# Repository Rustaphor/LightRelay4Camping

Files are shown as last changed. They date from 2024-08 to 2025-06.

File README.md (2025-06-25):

LightRelay4Camping ⛺🌳⛰️
==========================
 

Проект аналогового микромощного фотореле с питанием от PowerBank (USB Type-C) для управления включение-отключение USB-гирлянд
(напряжения питания 5В) в ночное время суток в широким диапазоне регулировки пороговых уровней чувствительности к темноте.
Это простое и надежное DIY устройство целиком аналоговое без прошивок, его несложно повторить начинающему радиолюбителю.
На фото ниже представлен внешний вид собранной электронной платы и устройства в корпусе.

Фото электронной платы сверху в корпусе

**Фото устройства в корпусе**

## Для чего нужно?
Устройство будет очень полезным в местах кемпинга и отдыха при освещении гирляндами с питанием от PowerBank-ов.
Светодиодные USB-гирлянды, украшающие палатку/автомобиль или другое место размещения на природе с помощью данного устройства
станут автономно-управляемые по уличной освещенности. Самостоятельно включаться в ночное время суток и также отключаться
на рассвете, тем самым экономя заряд PowerBank-а.

[Go to documentation][1]

## Особенности девайса
Фотореле спроектировано просто и надежно. Технически проект представляет несложную реализацию электронной аналоговой
схемотехники (см. _принципиальную схему_) и стандартной цифровой логики (без микроконтроллеров и прошивок), что делает прибор
микро мощным малопотребляемым. А также последнее обстоятельство делает удобным повторение DIY, например в учебной практике.
Для построения электронной схемы выбраны современные широкодоступные электронные компоненты. Ниже кратко представлены
основные достоинства устройства:

- :white_check_mark: Сверхнизкое энергопотребление, значение всего 1мА (в светлое время);
- :white_check_mark: Широкий диапазон регулирования чувствительности срабатывания. От крайне темного, едва видное глазу до рассвета,
когда уже гирлянды не нужны;
- :white_check_mark: Питание 5В от повербанка USB Type-C;
- :white_check_mark: Встроенный супперконденсатор и схема его заряда для решение проблемы самоотключения PowerBank-ов. В ждущем режиме фотореле питается от собственного суперконденсатора.
  Емкости суперконденсатора хватает на 4 часа автономной работы;
- :white_check_mark: Небольшая встроенная временная задержка включения/отключения для минимизации ложных срабатываний часто меняющейся
освещенности, например, под качающимися кронами деревьев;
- 🎁 В качестве бонуса к проектe приложены исходные файлы корпуса для 3D-печати. Корпус имеет следующие особенности:
  - ☔︎ Влагозащищенный
  - 👁 Поворотный глазок с датчиком освещенности (направляется в небо)
  - 🧲 Магнитное крепление 
  
Фото электронной платы сверху в корпусе

**Фото устройства со снятой верхней крышкой**

> [!TIP]
> PowerBank-и имеют особенность работы. Они предназначены для питания сравнительно мощных нагрузок. Если ток
> потребления нагрузкой слишком мал (менее 50…100мА), то через небольшой промежуток времени PowerBank переходит в режим
> «сна» (выключается), нагрузка полностью обесточивается.

:blue_book: [Полная техническая документация][1] содержит подробное описание принципа работы, инструкции к изготовлению.

> [!IMPORTANT]
> Подключение устройства к PowerBank-у рекомендуется кабелем *USB: type-C + type-C*. При использовании кабеля *USB: Type-A + Type-C*, автоматическое включение
> PowerBank-а негарантировано (зависит от особенностей конкретного PowerBank-а).

<details>
<summary>:paperclip: Файлы проекта</summary>

## Файлы проекта
Проект состоит из нижеследующих файлов и папок:

**Проектные файлы электронной схемы и печатной платы** в формате [KiCad EDA](https://www.kicad.org/) v8.0, содержат
электронную схему, печатную плату (ПП), правила её трассировки, сопутствующие компоненты (посадочные места, 3D-модели).

```
📄 Camping-LightRelay.kicad_*
📄 lsensor-module.kicad_sch
📄 custom.kicad_sym
📄 fp-lib-table
📄 sym-lib-table
📂 [lib.pretty]
📂 [3dshapes]
```

**Файлы симуляции**
Файлы симуляция [SPICE](https://ru.wikipedia.org/wiki/SPICE_(%D1%81%D0%B8%D0%BC%D1%83%D0%BB%D1%8F%D1%82%D0%BE%D1%80_%D1%8D%D0%BB%D0%B5%D0%BA%D1%82%D1%80%D0%BE%D0%BD%D0%BD%D1%8B%D1%85_%D1%81%D1%85%D0%B5%D0%BC))
отдельных узлов содержатся в отдельной директории

```
📂 [Sims]
```
</details>

[1]: https://github.com/Rustaphor/LightRelay4Camping/wiki "Перейти в раздел Wiki"

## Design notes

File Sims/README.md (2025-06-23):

## Файлы симуляции схемы


Файлы в этой директории предназначены для программного продукта симулятора электронных схем [Micro-Cap 12][1]. Чтобы открыть требуется установить соответствующее ПО
со стандартными библиотеками компонентов. Файлы в данной директории не локализованы и не содержат библиотечных компонентов. Данные файлы полезны если требуется внести
какие-то изменения в работу схемы, заменить аналогами или пересчитать номиналы. Если Вам просто нужно повторить уже готовую схему, эти файлы и директория не нужны.

> [!IMPORTANT]
> Раздел предназначен для опытных пользователей, понимающих теорию цепей и принципы разработки электронных устройств посредством моделирования
> [SPICE](https://ru.wikipedia.org/wiki/SPICE_(%D1%81%D0%B8%D0%BC%D1%83%D0%BB%D1%8F%D1%82%D0%BE%D1%80_%D1%8D%D0%BB%D0%B5%D0%BA%D1%82%D1%80%D0%BE%D0%BD%D0%BD%D1%8B%D1%85_%D1%81%D1%85%D0%B5%D0%BC))-подобным
> Симуляция электронных устройств выходит за рамки настоящей технической документации, начинающему пользователю многое будет непонятно. :exploding_head:

Подробная [техническая документация по симуляции в технической документации](https://github.com/Rustaphor/LightRelay4Camping/wiki/%D0%9C%D0%BE%D0%B4%D0%B5%D0%BB%D0%B8%D1%80%D0%BE%D0%B2%D0%B0%D0%BD%D0%B8%D0%B5-%D1%81%D1%85%D0%B5%D0%BC%D1%8B)

[1]: https://ru.wikipedia.org/wiki/Micro-Cap "Micro-Cap wiki"

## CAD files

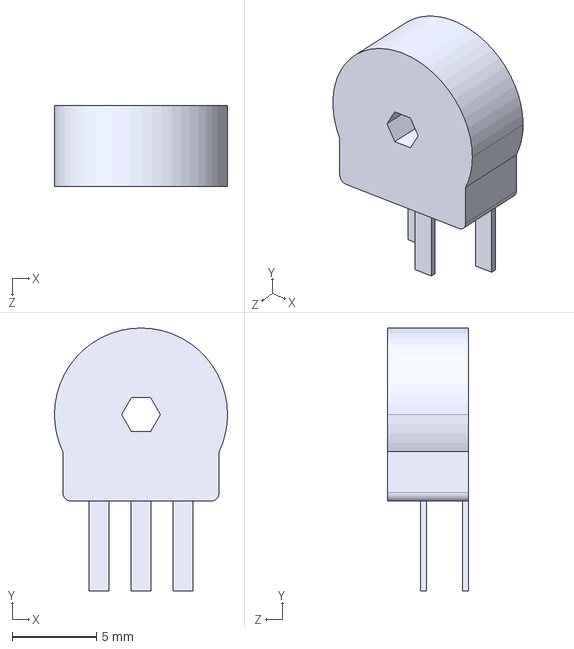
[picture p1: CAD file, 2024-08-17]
3dshapes/PTN10-AH.STEP
10.3 x 15.7 x 4.80 mm

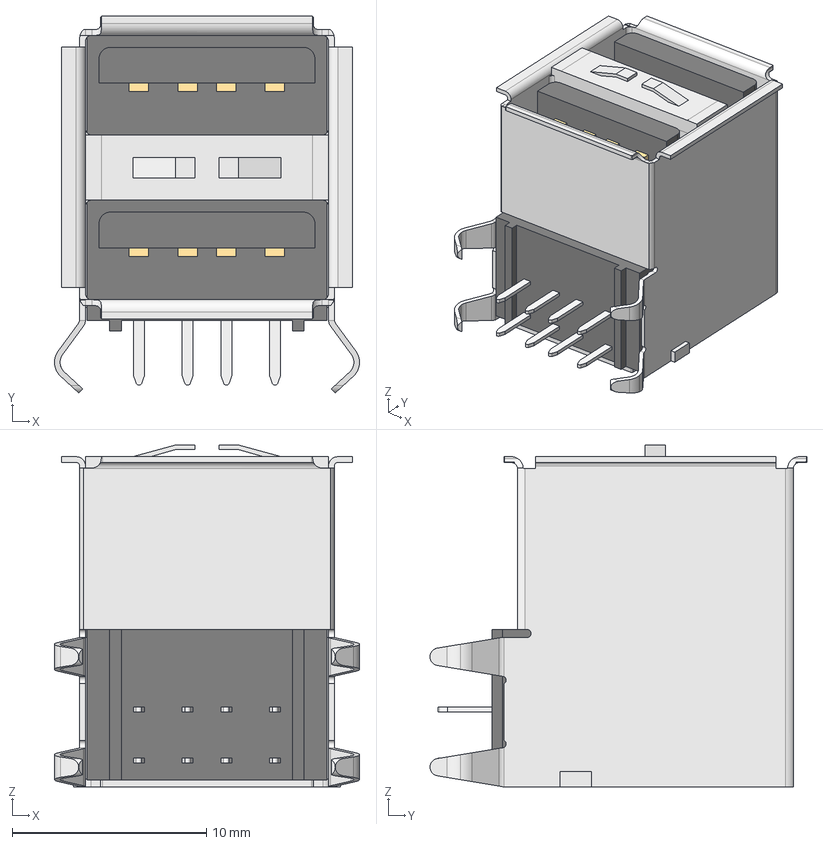
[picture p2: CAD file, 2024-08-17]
3dshapes/usb_a_dual_port_dip.stp
15.7 x 19.4 x 17.6 mm

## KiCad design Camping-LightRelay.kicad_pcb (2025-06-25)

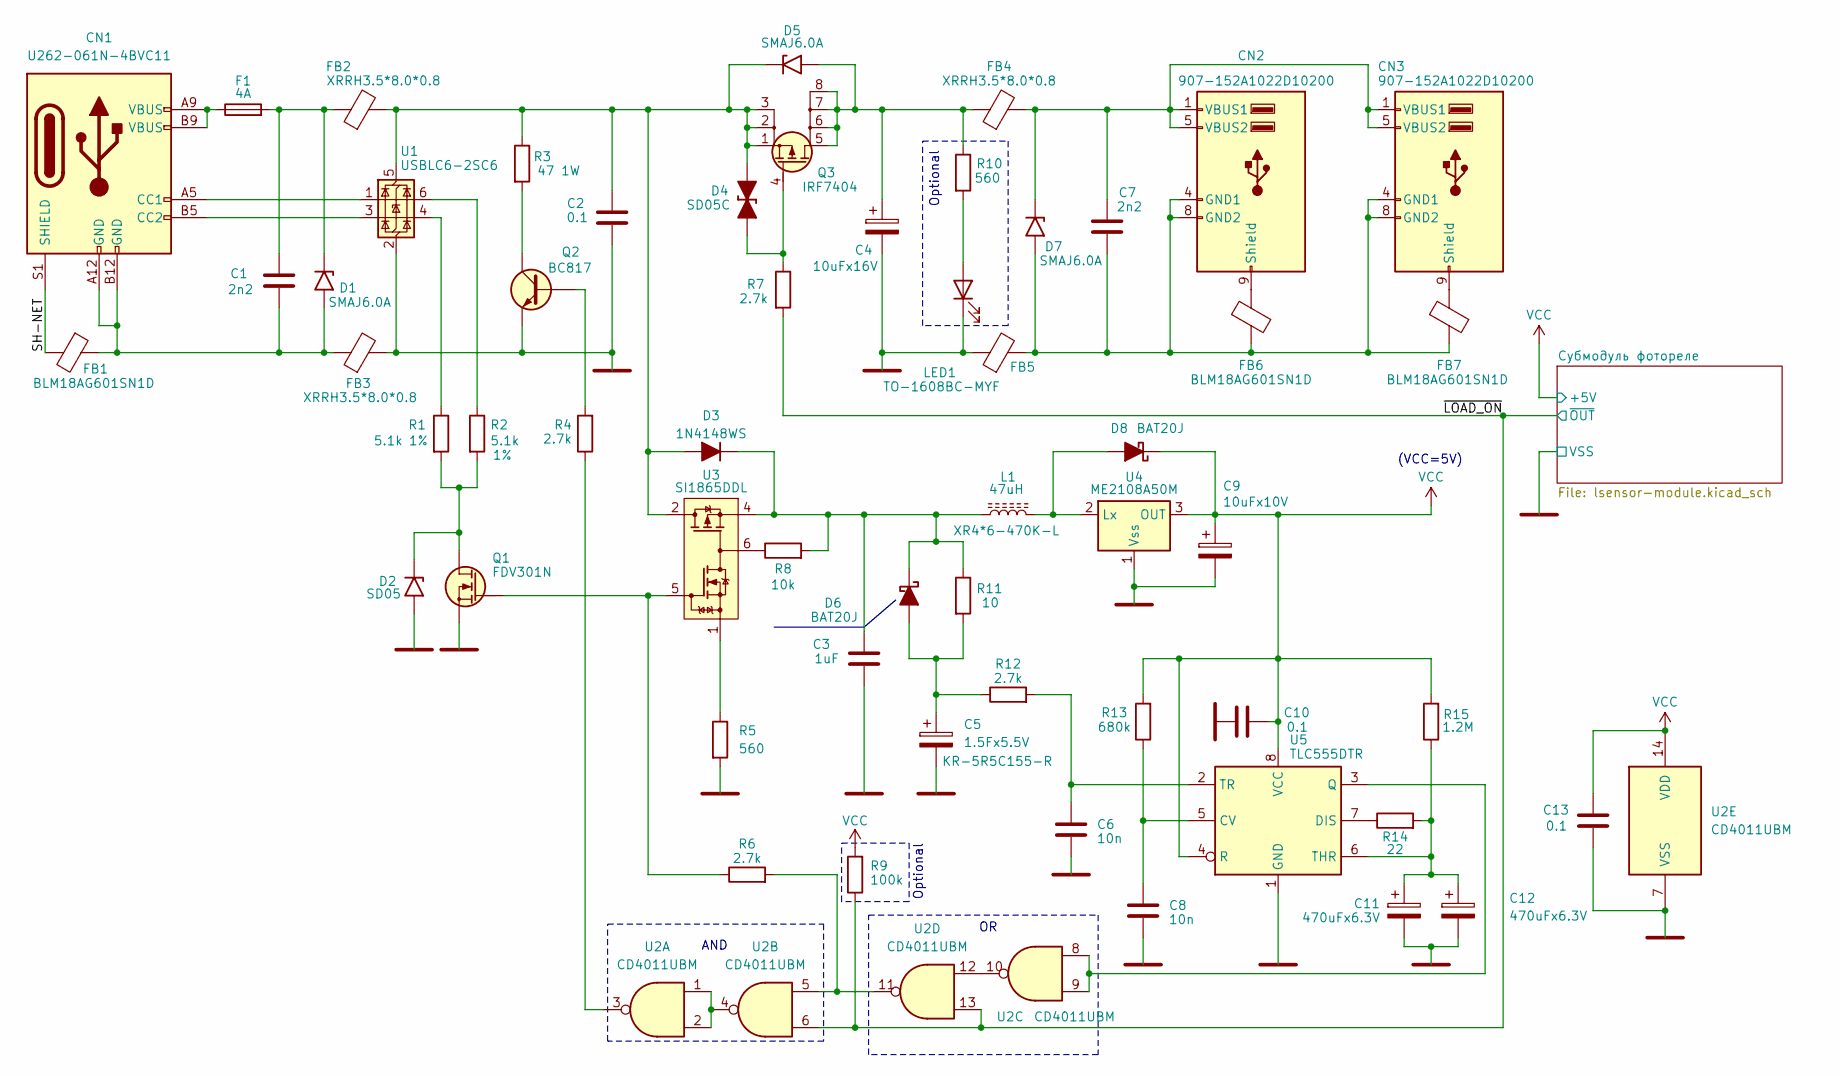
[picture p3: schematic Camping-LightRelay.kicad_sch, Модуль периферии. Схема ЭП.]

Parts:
C1, C7: 2n2; C_Disc_D7.5mm_W5.0mm_P7.50mm; Part Number CY2222MD1PEE47J2A8
C2, C10, C13: 0.1; C_0603_1608Metric
C3: 1uF; C_0805_2012Metric
C4: 10uFx16V; CP_EIA-3216-12_Kemet-S_Pad1.58x1.35mm_HandSolder; Part Number CA45-B010K107T
C5: 1.5Fx5.5V; Eaton_KR-5R5C155; Part Number KR-5R5C155-R
C6, C8: 10n; C_0603_1608Metric
C9: 10uFx10V; CP_EIA-3216-12_Kemet-S_Pad1.58x1.35mm_HandSolder; Part Number TC212A106K010Y
C11, C12: 470uFx6.3V; CP_EIA-7343-31_Kemet-D_Pad2.25x2.55mm_HandSolder; Part Number TAJD477K006RNJ
CN1: U262-061N-4BVC11; USB_C_Receptacle_GCT_USB4125-xx-x-0190_6P_TopMnt_Horizontal
CN2, CN3: 907-152A1022D10200; USB_A_DUAL_PORT_Horizontal_Stacked
D1, D5, D7: SMAJ6.0A; D_SMA
D2: SD05; D_SOD-323_HandSoldering
D3: 1N4148WS; D_SOD-323_HandSoldering
D4: SD05C; D_SOD-323_HandSoldering
D6, D8: BAT20J; D_SOD-323_HandSoldering
F1: 4A; Fuse_1206_3216Metric_Pad1.42x1.75mm_HandSolder
FB1, FB6, FB7: BLM18AG601SN1D; L_0603_1608Metric
FB2, FB3, FB4, FB5: XRRH3.5*8.0*0.8; Ferrite_L8.0mm_D3.5mm_P3.81mm_Vertical
L1: 47uH; L_Radial_D6.0mm_P4.00mm; Part Number XR4*6-470K-L
LED1: TO-1608BC-MYF; LED_0603_1608Metric_Pad1.05x0.95mm_HandSolder
Q1: FDV301N; SOT-23
Q2: BC817; SOT-23
Q3: IRF7404; SO-8_3.9x4.9mm_P1.27mm
R1, R2: 5.1k; R_0603_1608Metric_Pad0.98x0.95mm; Tolerance 1%
R3: 47 1W; R_Axial_DIN0309_L9.0mm_D3.2mm_P2.54mm_Vertical
R4, R6, R12: 2.7k; R_0603_1608Metric_Pad0.98x0.95mm
R5: 560; R_0603_1608Metric_Pad0.98x0.95mm
R7: 2.7k; R_0603_1608Metric
R8: 10k; R_0603_1608Metric_Pad0.98x0.95mm
R9: 100k; R_0603_1608Metric_Pad0.98x0.95mm
R10: 560; R_0603_1608Metric
R11: 10; R_0805_2012Metric_Pad1.15x1.40mm
R13: 680k; R_0603_1608Metric_Pad0.98x0.95mm
R14: 22; R_0603_1608Metric_Pad0.98x0.95mm
R15: 1.2M; R_0603_1608Metric_Pad0.98x0.95mm
U1: USBLC6-2SC6; SOT-23-6
U2: CD4011UBM; SOIC-14_3.9x8.7mm_P1.27mm
U3: SI1865DDL; SOT-363_SC-70-6
U4: ME2108A50M; SOT-23-3
U5: TLC555DTR; SOIC-8_3.9x4.9mm_P1.27mm

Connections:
/SH-NET: CN1.S1 (SHIELD), FB1.2
/~LOAD_ON: R7.2, R9.1, U2.6, U2.13; also elsewhere on the board
GNDE: C2.2, C3.2, C4.2, C5.2, C6.2, C8.2, C9.2, C10.1, C11.2, C12.2, C13.2, D2.2 (A2), FB3.2, FB5.1, LED1.1 (K), Q1.2 (S), Q2.2 (E), R5.2, U1.2 (GND), U2.7 (VSS), U4.1 (Vss), U5.1 (GND); also elsewhere on the board
unnamed: CN1.A5 (CC1), U1.1 (I/O1)
unnamed: CN1.B5 (CC2), U1.3 (I/O2)
unnamed: CN1.A9 (VBUS), CN1.B9 (VBUS), F1.1
unnamed: C7.2, CN2.4 (GND1), CN2.8 (GND2), CN3.4 (GND1), CN3.8 (GND2), D7.2 (A2), FB5.2, FB6.1, FB7.1
unnamed: CN2.9 (Shield), FB6.2
unnamed: C7.1, CN2.1 (VBUS1), CN2.5 (VBUS2), CN3.1 (VBUS1), CN3.5 (VBUS2), D7.1 (A1), FB4.2
unnamed: CN3.9 (Shield), FB7.2
unnamed: C1.1, D1.1 (A1), F1.2, FB2.1
unnamed: C1.2, CN1.A12 (GND), CN1.B12 (GND), D1.2 (A2), FB1.1, FB3.1
unnamed: D2.1 (A1), Q1.3 (D), R1.2, R2.2
unnamed: C2.1, D3.2 (A), D4.1 (K), D5.1 (A1), FB2.2, Q3.1 (S), Q3.2 (S), Q3.3 (S), R3.1, U1.5 (VBUS), U3.2 (D2), U3.3 (D2)
unnamed: C3.1, D3.1 (K), D6.1 (K), L1.1, R8.2, R11.1, U3.4 (S2)
unnamed: D4.2 (A), Q3.4 (G), R7.1
unnamed: C4.1, D5.2 (A2), FB4.1, Q3.5 (D), Q3.6 (D), Q3.7 (D), Q3.8 (D), R10.1
unnamed: C5.1, D6.2 (A), R11.2, R12.1
unnamed: D8.2 (A), L1.2, U4.2 (Lx)
unnamed: LED1.2 (A), R10.2
unnamed: Q1.1 (G), R6.1, U3.5 (on/off)
unnamed: Q2.1 (B), R4.2
unnamed: Q2.3 (C), R3.2
unnamed: R1.1, U1.4 (I/O2)
unnamed: R2.1, U1.6 (I/O1)
unnamed: R4.1, U2.3
unnamed: R5.1, U3.1
unnamed: R6.2, U2.5, U2.11
unnamed: R8.1, U3.6
unnamed: U2.1, U2.2, U2.4
unnamed: U2.10, U2.12
unnamed: C8.1, R13.1, U5.5 (CV)
unnamed: R14.1, U5.7 (DIS)
unnamed: U2.8, U2.9, U5.3 (Q)
unnamed: C11.1, C12.1, R14.2, R15.1, U5.6 (THR)
unnamed: C6.1, R12.2, U5.2 (TR)
VCC: C9.1, C10.2, C13.1, D8.1 (K), R9.2, R13.2, R15.2, U2.14 (VDD), U4.3 (OUT), U5.4 (R), U5.8 (VCC); also elsewhere on the board

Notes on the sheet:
Optional
AND
(VCC=5V)

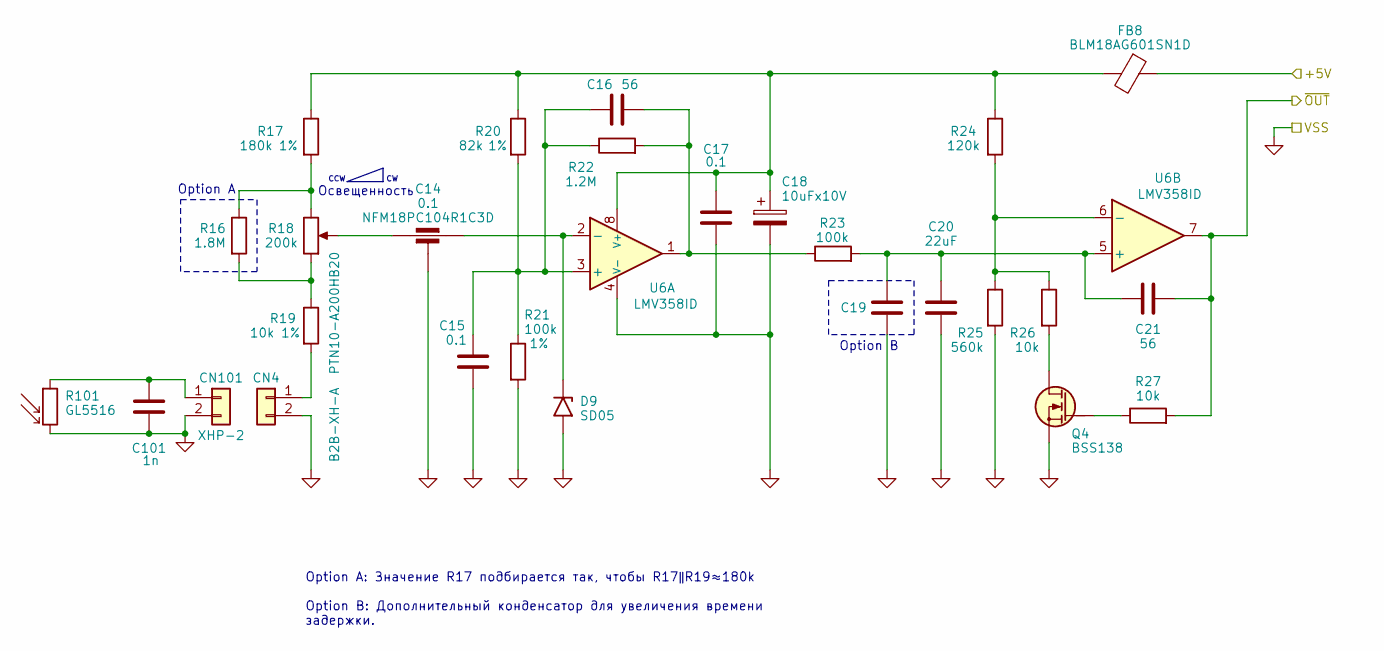
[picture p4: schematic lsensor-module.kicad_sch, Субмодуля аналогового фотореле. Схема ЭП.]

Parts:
C14: 0.1; C_0603_3-terminal; Part Number NFM18PC104R1C3D
C15, C17: 0.1; C_0603_1608Metric
C16, C21: 56; C_0603_1608Metric
C18: 10uFx10V; CP_EIA-3216-10_Kemet-I_Pad1.58x1.35mm_HandSolder; Part Number TC212A106K010Y
C19: 10uF; C_0805_2012Metric
C20: 22uF; C_0805_2012Metric
C101: 1n; C_0603_1608Metric
CN4: B2B-XH-A; JST_XH_B2B-XH-AM_1x02_P2.50mm_Vertical
CN101: XHP-2; PinSolder_1x2_P2.54mm
D9: SD05; D_SOD-323_HandSoldering
FB8: BLM18AG601SN1D; L_0603_1608Metric
Q4: BSS138; SOT-23
R16: 1.8M; R_0603_1608Metric
R17: 180k; R_0603_1608Metric; Tolerance 1%
R18: 200k; TRIM_PTN10-A01HB20; Part Number PTN10-A200HB20
R19: 10k; R_0603_1608Metric; Tolerance 1%
R20: 82k; R_0603_1608Metric; Tolerance 1%
R21: 100k; R_0603_1608Metric; Tolerance 1%
R22: 1.2M; R_0603_1608Metric
R23: 100k; R_0603_1608Metric
R24: 120k; R_0603_1608Metric
R25: 560k; R_0603_1608Metric
R26, R27: 10k; R_0603_1608Metric
R101: GL5516; R_LDR_5.1x4.3mm_P3.4mm_Vertical
U6: LMV358ID; SO-8_3.9x4.9mm_P1.27mm

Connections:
/~LOAD_ON: C21.2, R27.2, U6.7; also elsewhere on the board
GND2: C101.2, CN101.2, R101.2
GNDE: C14.2, C15.2, C17.2, C18.2, C19.2, C20.2, CN4.2, D9.2 (A2), Q4.2 (S), R21.2, R25.2, U6.4 (V-); also elsewhere on the board
unnamed: C16.2, R22.2, R23.1, U6.1
unnamed: CN4.1, R19.2
unnamed: C101.1, CN101.1, R101.1
unnamed: C14.3, D9.1 (A1), U6.2 (-)
unnamed: Q4.3 (D), R26.2
unnamed: Q4.1 (G), R27.1
unnamed: R16.2, R18.1 (A), R19.1
unnamed: R16.1, R17.2, R18.3 (E)
unnamed: C14.1, R18.2 (S)
unnamed: C15.1, C16.1, R20.2, R21.1, R22.1, U6.3 (+)
unnamed: C17.1, C18.1, FB8.2, R17.1, R20.1, R24.1, U6.8 (V+)
unnamed: C19.1, C20.1, C21.1, R23.2, U6.5 (+)
unnamed: R24.2, R25.1, R26.1, U6.6 (-)
VCC: FB8.1; also elsewhere on the board

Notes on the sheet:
Option A: Значение R17 подбирается так, чтобы R17ǁR19≈180k Option B: Дополнительный конденсатор для увеличения времени задержки.
Option A
CCW
Освещенность
Option B

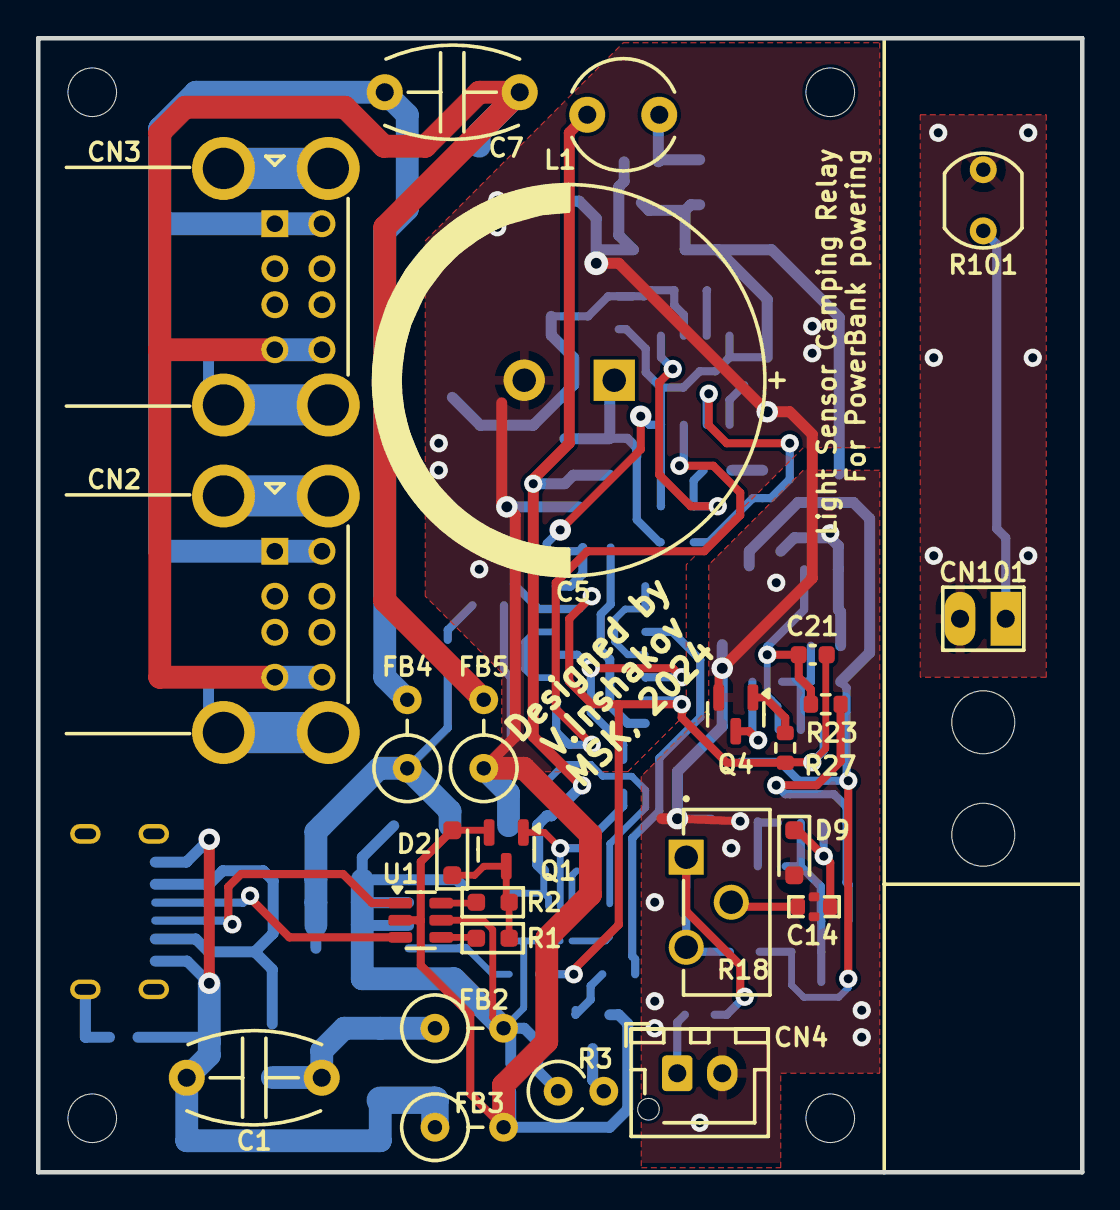
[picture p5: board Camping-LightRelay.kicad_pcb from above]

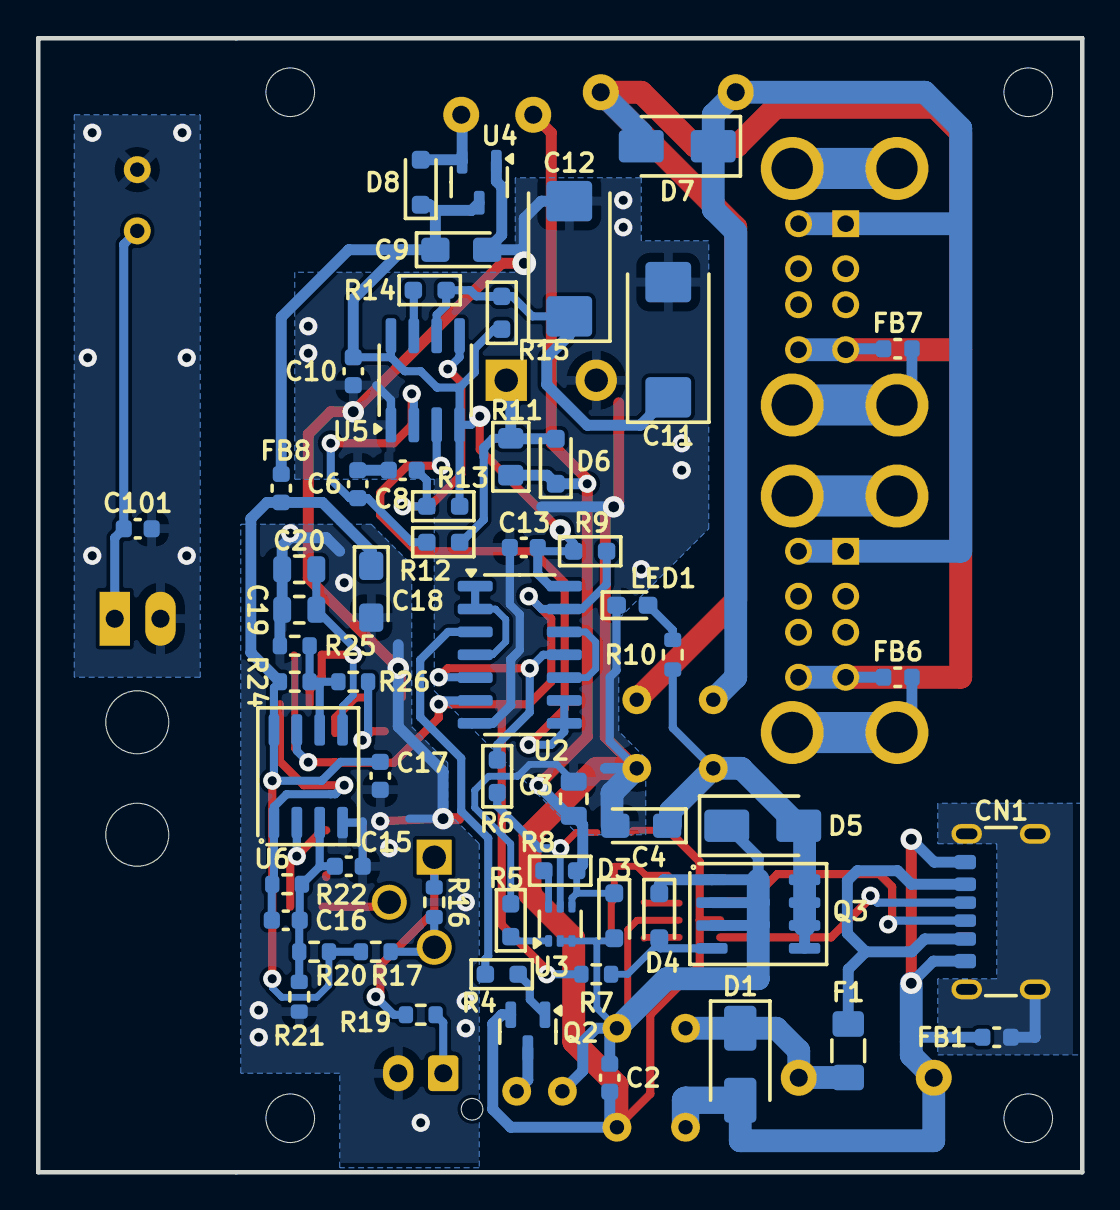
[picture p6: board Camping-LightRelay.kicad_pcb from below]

Board: 2 copper layers, 58.0 x 63.0 mm, 91 parts (59 on the bottom side), 51 nets.

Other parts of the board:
HOLE101, HOLE102: MountingHole_3.5mm
MH1, MH1#2, MH1#3, MH3: MountingHole_2.7mm_M2.5

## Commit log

2024-08-17 Правка файла .gitignore
    Добавление ненужных файлов в исключения
2024-08-17 Симуляция электросхемы
    Создание и симуляция SPICE основных блоков фотореле.
2024-08-17 Инвертирование компаратора фотосенсора
    Первоначальная схема сенсора неудобна. Требуется неинвертированный сигнал на выходе; датчик высокоомный и лучше "тянуть" его ближе к "земле".
2024-08-17 Добавление э/схемы и п/платы
    Разработка и схемы и печатной платы с сопутствующими библиотечными компонентами. Схема не собиралась и не тестировалась.
    [Camping-LightRelay.kicad_pcb, Camping-LightRelay.kicad_sch, PTN10-AH.STEP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]
2024-09-24 Добавление э/схемы, SI
    Разработка алгоритма и симуляционной схемы контроллера PowerBank. Проверка работы TLC555 на макетке вживую. Создание символа SI1865
    [Camping-LightRelay.kicad_pcb, Camping-LightRelay.kicad_sch, PTN10-AH.STEP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]
2024-09-30 Отрисовка субмодуля управления питанием
    Принципиальная схема (KiCAD) субмодуля управления PowerBank-ом. Создание электронных компонентов в базе. Выбор и назначение посадочных мест.
    [Camping-LightRelay.kicad_sch, module-supercap-ps.kicad_sch]
2024-10-05 Работа со схемой модуля
    Частичная отрисовка и назначение посадочных мест субмодуля питания от PowerBank. *Работа продолжается*.
    [Camping-LightRelay.kicad_pcb, Camping-LightRelay.kicad_sch, module-supercap-ps.kicad_sch]
2024-10-07 Переделка топологии субмодулей
    Фотореле вынесен в отдельный субмодуль, как дополнительная печатная плата. Схема управления PowerBank-ом перенесена на силовую плату с другими компонентами.
    [Camping-LightRelay.kicad_pcb, Camping-LightRelay.kicad_sch, lsensor-module.kicad_sch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]
2024-10-07 Назначение посадочных мест схемы
    Дорисовка недостающий э/компонентов и важных 3D-моделей
    [Camping-LightRelay.kicad_pcb, Camping-LightRelay.kicad_sch, lsensor-module.kicad_sch]
2024-10-08 Переход на 2-х стороннюю ПП
    Топология ПП выбрана двусторонняя в виду миниатюрности устройства. Изменение посадочных мест под новую топологию.
    [Camping-LightRelay.kicad_pcb, Camping-LightRelay.kicad_sch]
2024-10-10 Разводка ПП, трассировка, оптимизация
    Отказ от идеи с субмодулем, все разводится на двухсторонней ПП.
    Вынос аналогового фотореле на отдельный лист схемы.
    Разводка двусторонней ПП
    [Camping-LightRelay.kicad_pcb, Camping-LightRelay.kicad_sch, lsensor-module.kicad_sch]
2024-10-12 Доделка ПП до финала
    Проверка DRC, подгонка автоправил трассирования дорожек. Корректировка технических ограничений ПП. Расчет номиналов конденсаторов C11, C12.
    [Camping-LightRelay.kicad_pcb, Camping-LightRelay.kicad_sch, lsensor-module.kicad_sch]
2024-11-24 Первая сборка production
    Сборка всей конструкции и проверка на ПП, проверка работы
    * Правка посадочного места ионистор C3 и печатной платы для него
    * Замена D3 на обычный 1N4148 из-за утечек Шоттки
    * Замена стабилитрона D4 на двойной TVS-диод, т.к. обнаружился обходной ток от внутреннего DC/DC преобразователя
    [Camping-LightRelay.kicad_pcb, Camping-LightRelay.kicad_sch, lsensor-module.kicad_sch]
2024-11-25 Добавление ReaadMe
    Добавление README в корневую директорию
    Удаление файла DNO
2024-12-28 Исправление диаметров отверстий
    Отверстия пропускания кабеля датчика освещенности слишком малы. Увеличено до 3.5мм
    [Camping-LightRelay.kicad_pcb]
2025-02-01 Страница приветствия и симуляция
    Обновляем страницу приветствия и небольшие правки симуляции
2025-06-23 Мелкий рефакторинг
    - Обновление Readme.md
    - Правки в печатную плату
    - Переименование сигналов
    - добавление исключений в .gitignore
    [Camping-LightRelay.kicad_pcb, Camping-LightRelay.kicad_sch, lsensor-module.kicad_sch]
2025-06-25 Обновление перед публикацией
    - Удаление лишнего файла симуляции
    - Рефакторинг электрической схемы и печатной платой.
    - Добавление файла симуляции разряда ионистора.
    - Удаление лишних захламляющих файлов
    - Рефакторинг симуляции схем
    - Обновление описания Readme
    [Camping-LightRelay.kicad_pcb, Camping-LightRelay.kicad_sch, lsensor-module.kicad_sch]
2025-06-29 Изменение номинала резистора R3
    Возможна нестабильная работа запуска PowerBank-ов при номинале *47 Ом*. Уменьшено до *43* Ом, чтобы ток составлял _100мА_
    [Camping-LightRelay.kicad_sch]
